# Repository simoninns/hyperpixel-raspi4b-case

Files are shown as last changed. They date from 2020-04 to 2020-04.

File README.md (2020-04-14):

# Hyperpixel 4.0 touch and Raspberry Pi 4B case (with Prusa MK3S bracket)
This project provides a 3D printable case for the Hyperpixel 4.0 touch display and Raspberry Pi 4 B.  The case features a universal mounting system; a bracket for the Prusa i3 MK3S/MMU2S is also provided.

Note: This project is GPLv3 open-source. The github repository for the model (containing the complete OpenSCAD project) can be found at https://github.com/simoninns/hyperpixel-raspi4b-case

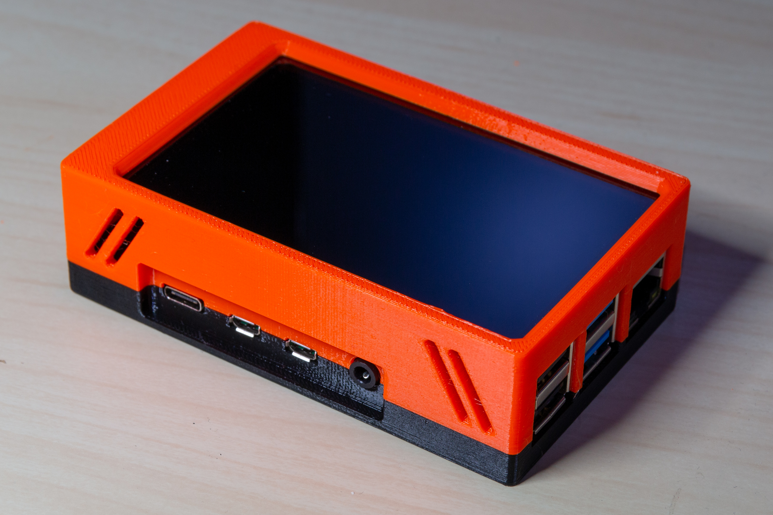
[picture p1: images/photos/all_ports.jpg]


# Overview

The case is designed in two parts (the upper and lower case) which snap together without the need for screws.  The Raspberry Pi and Hyperpixel display are held in place using the original mounting hardware provided with the Hyperpixel.

The project also includes an accurate model of the Raspberry Pi 4 B:

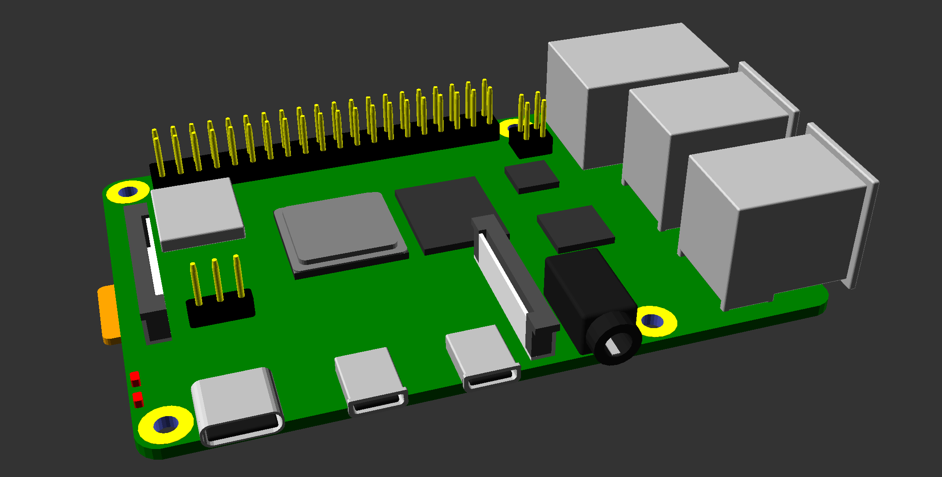
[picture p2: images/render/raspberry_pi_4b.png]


As well as an accurate model of the Hyperpixel 4.0 (rectangular) touch screen display:

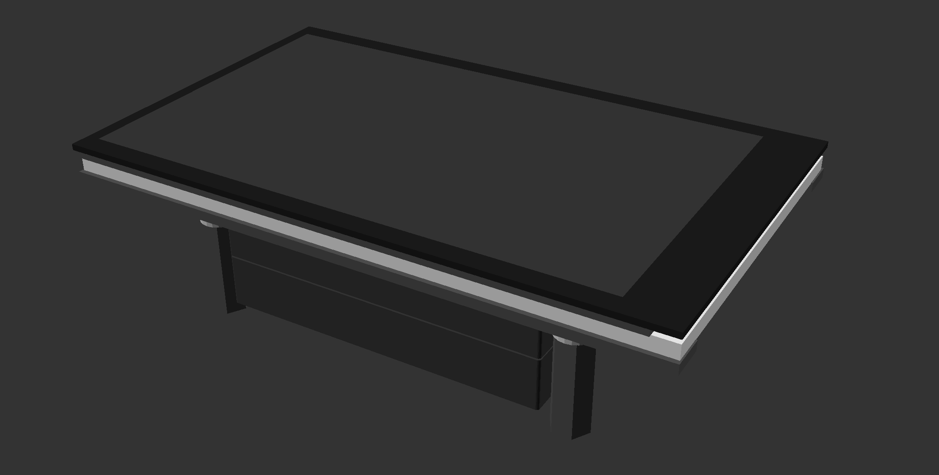
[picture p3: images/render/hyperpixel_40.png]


# Assembly instructions

The Hyperpixel 4.0 display should have both the GPIO extender and the 4 support posts mounted.  Attach the display to the Raspberry Pi.  Flip the joined boards screen down and place the lower case part onto the 4 posts (ensure the SD card is removed).  Screw together using the M2.5x5mm screws provided with the Hyperpixel display.  The SD card can be reinserted through the provided slot in the lower case.

If required the additional bracket (for the Prusa MK3S) can also be attached.  Ensure there are no screws in the lower case, then press the bracket into place.  The bracket should be secured using M2.5x8mm screws.  Note that the case is designed so brackets can be mounted on either side of the case in both up and down orientations.



The upper case is attached to the lower case by first lowering the connector-side of the case over the display (as it is too thick to be pressed straight down).  Then rotate the other side of the upper case over the display and clip the upper and lower cases together.

The lower case provides two 1.8mm holes for the LEDs.  You can optionally use two short lengths of transparent/clear 1.75mm filament to act as light-pipes.  These can be glued in place (using superglue) into the mount in the lower case.  This allows a wider viewing angle for the LEDs.

# Printing instructions

## Overview

The model has been printed and tested on the Prusa MK3S/MMU2S printer using PETG filament. All parts fit on a 20x20 printing bed.

The OpenSCAD source files provide a parameter interface that allows you to render either the whole model or the individual parts (ready for STL (or other 3D format) export).  This requires OpenSCAD 2019.05 or later.

## Recommended print settings
### Lower case
* Number required: 1
* Material: Prusament PETG (Prusa Jet Black)
* Layer: 0.20mm (Quality)
* Infill: 15%
* Supports: Support on build plate only
* Print time (approximate): 1h 51m
* Notes: None

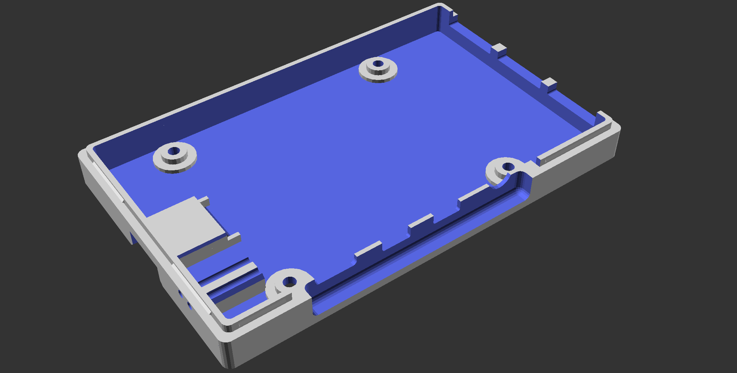
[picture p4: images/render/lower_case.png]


### Upper case
* Number required: 1
* Material: Prusament PETG (Prusa Orange)
* Layer: 0.20mm (Quality)
* Infill: 15%
* Supports: None
* Print time (approximate): 2h 24m
* Notes: None

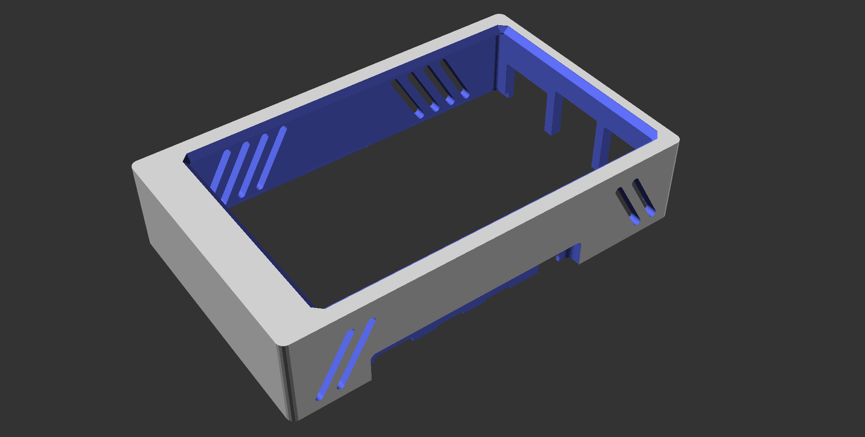
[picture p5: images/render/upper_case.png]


### Bracket
* Number required: 1
* Material: Prusament PETG (Prusa Orange)
* Layer: 0.20mm (Quality)
* Infill: 15%
* Supports: Everywhere
* Print time (approximate): 1h 49m
* Notes: Fits Prusa i3 MK3S and MMU2S

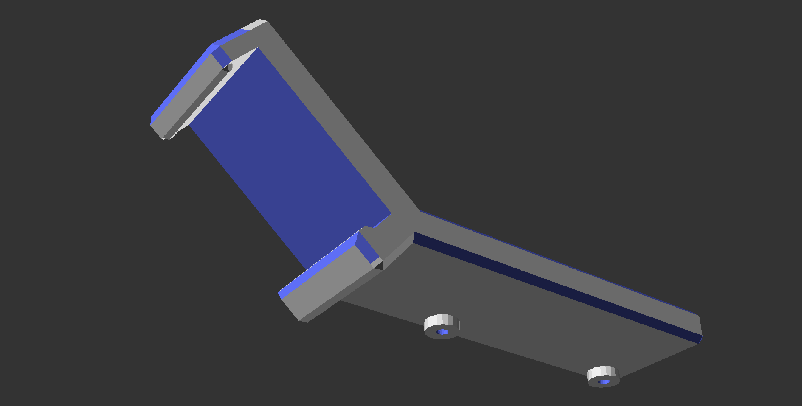
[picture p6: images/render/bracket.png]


### Desk stand
* Number required: 2
* Material: Prusament PETG (Prusa Orange)
* Layer: 0.20mm (Quality)
* Infill: 15%
* Supports: Everywhere
* Print time (approximate): 1h 1m
* Notes: Places the screen at a 30 degree angle for ease of use on a desk.

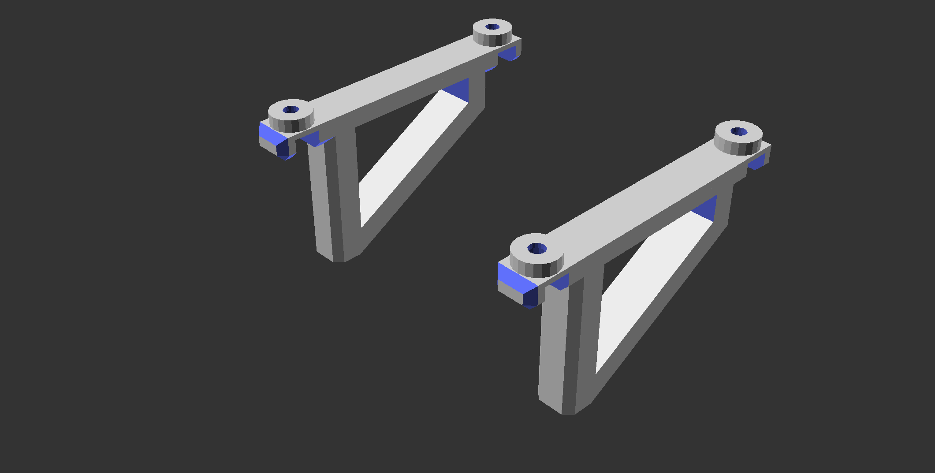
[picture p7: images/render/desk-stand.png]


# Author

The Hyperpixel 4.0 touch and Raspberry Pi 4B case is designed and maintained by Simon Inns.

# Licensing

## OpenSCAD source files - software license (GPLv3)

    This is free software: you can redistribute it and/or modify
    it under the terms of the GNU General Public License as published by
    the Free Software Foundation, either version 3 of the License, or
    (at your option) any later version.
    
    This program is distributed in the hope that it will be useful,
    but WITHOUT ANY WARRANTY; without even the implied warranty of
    MERCHANTABILITY or FITNESS FOR A PARTICULAR PURPOSE.  See the
    GNU General Public License for more details.
    
    You should have received a copy of the GNU General Public License
    along with this program.  If not, see <http://www.gnu.org/licenses/>.

## 3D model files - Creative Commons license (Creative Commons BY-SA 4.0)

Please see the following link for details: https://creativecommons.org/licenses/by-sa/4.0/

You are free to:

Share - copy and redistribute the material in any medium or format
Adapt - remix, transform, and build upon the material
for any purpose, even commercially.

This license is acceptable for Free Cultural Works.

The licensor cannot revoke these freedoms as long as you follow the license terms.

Under the following terms:

Attribution - You must give appropriate credit, provide a link to the license, and indicate if changes were made. You may do so in any reasonable manner, but not in any way that suggests the licensor endorses you or your use.

ShareAlike - If you remix, transform, or build upon the material, you must distribute your contributions under the same license as the original.

No additional restrictions - You may not apply legal terms or technological measures that legally restrict others from doing anything the license permits.

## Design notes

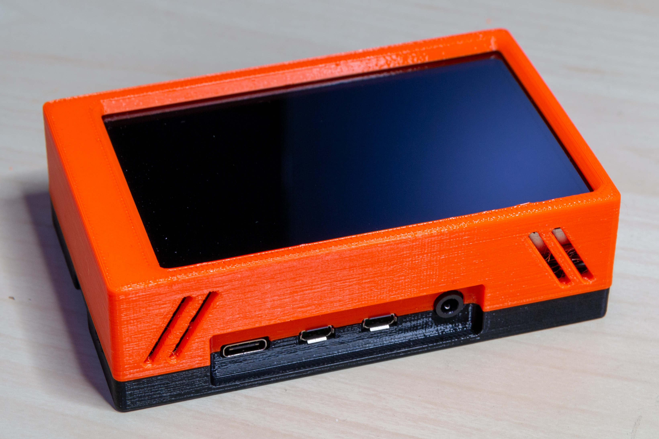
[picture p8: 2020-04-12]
images/photos/side_ports.jpg

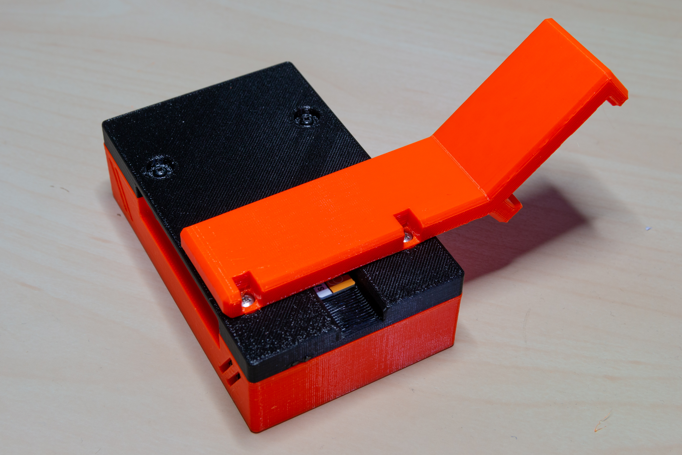
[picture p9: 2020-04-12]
images/photos/Back_with_bracket.jpg

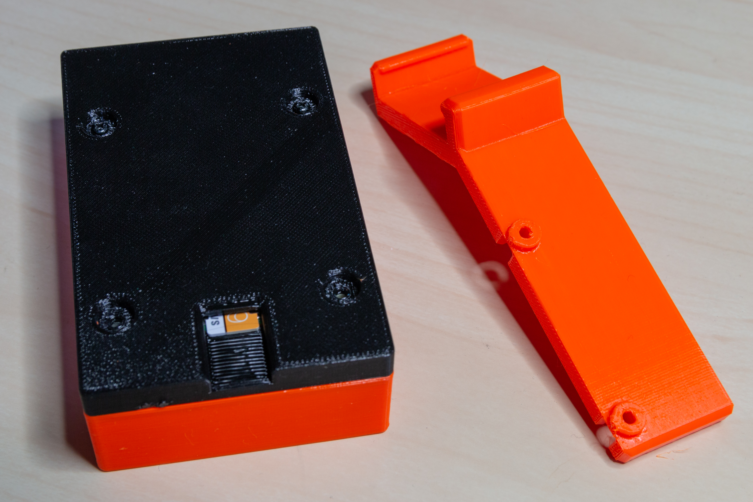
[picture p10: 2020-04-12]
images/photos/Back_unmounted_bracket.jpg

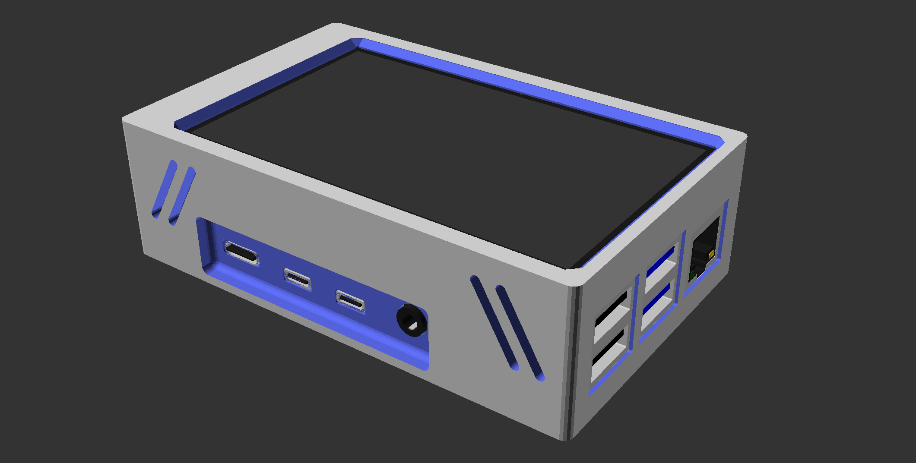
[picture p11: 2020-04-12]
images/render/complete_case.png

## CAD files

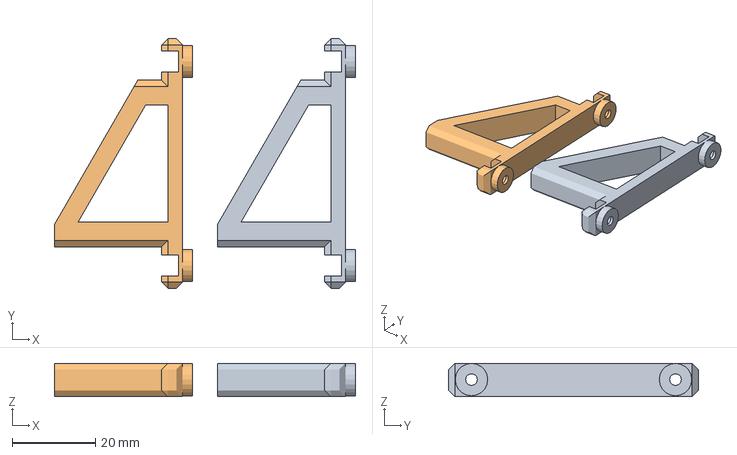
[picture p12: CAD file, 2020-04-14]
3mf/desk_stand.3mf
72.3 x 60.0 x 8.00 mm

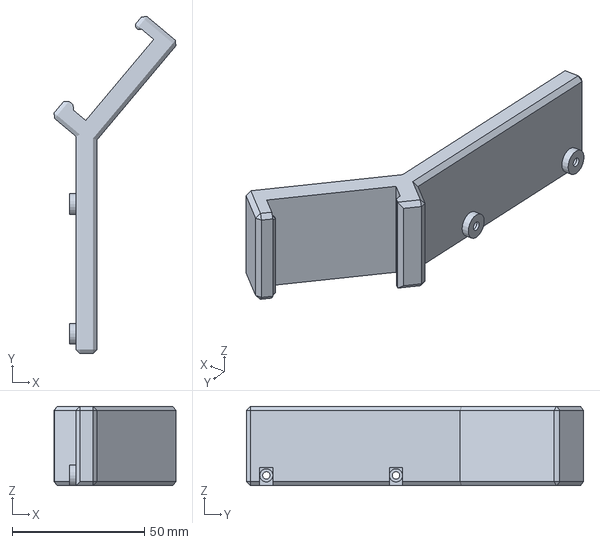
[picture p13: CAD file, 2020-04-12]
3mf/bracket.3mf
46.1 x 127.4 x 30.0 mm

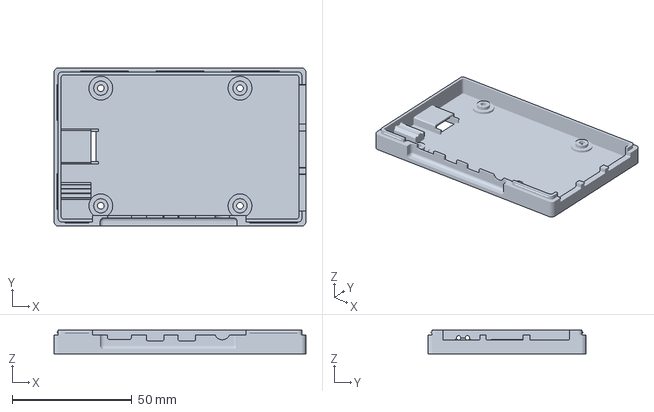
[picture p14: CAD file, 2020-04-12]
3mf/lower_case.3mf
105.0 x 66.0 x 10.0 mm

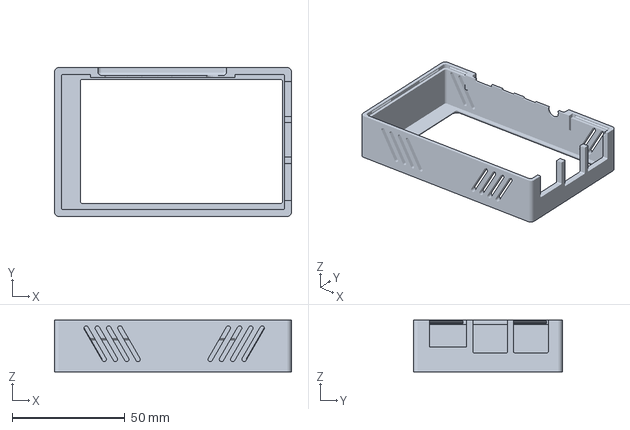
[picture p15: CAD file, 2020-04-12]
3mf/upper_case.3mf
105.0 x 66.0 x 23.0 mm

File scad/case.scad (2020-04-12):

/************************************************************************

	case.scad
    
	Raspberry Pi 4B / Hyperpixel 4.0 case
    Copyright (C) 2020 Simon Inns
    
    This program is free software: you can redistribute it and/or modify
	it under the terms of the GNU General Public License as published by
	the Free Software Foundation, either version 3 of the License, or
	(at your option) any later version.
    
    This program is distributed in the hope that it will be useful,
    but WITHOUT ANY WARRANTY; without even the implied warranty of
    MERCHANTABILITY or FITNESS FOR A PARTICULAR PURPOSE.  See the
    GNU General Public License for more details.
    
    You should have received a copy of the GNU General Public License
    along with this program.  If not, see <http://www.gnu.org/licenses/>.
	
    Email: simon.inns@gmail.com
    
************************************************************************/

include <BOSL/constants.scad>
use <BOSL/transforms.scad>
use <BOSL/shapes.scad>

// The connector cutouts are in a module so they can be common to both
// the upper and lower case parts
module connector_cutouts()
{
    // Recess
    move([3.25,-11.5,-2.5]) cuboid([57,10,3.5+10], center=false, fillet = 1.5);

    // Power in
    move([6.25,-3.5,1.5]) cuboid([10,4,3.5], center=false, fillet = 1, edges=EDGES_Y_ALL);

    // HDMI
    move([22,-3.5,1.5]) {
        move([0.5,0,-0.5]) cuboid([7.25,4,3.25], center=false, fillet = 0.5, edges=EDGES_Y_ALL);
        move([13.75,0,-0.5]) cuboid([7.25,4,3.25], center=false, fillet = 0.5, edges=EDGES_Y_ALL);
    }

    // Audio
    move([51,-3.5,1.5]) {
        move([3.125,1,3.125]) rotate([90,0,0]) cyl(h=6, d=6.5);
    }

    // USB2
    move([85,1.25,1.25]) {
        move([0,0,0]) cuboid([6,15.5,16.75], center=false, fillet = 0.5, edges=EDGES_X_ALL);
    }

    // USB3
    move([85,19.25,1.25]) {
        move([0,0,0]) cuboid([6,15.5,16.75], center=false, fillet = 0.5, edges=EDGES_X_ALL);
    }

    // Ethernet
    move([85,37.5,1.25]) {
        move([0,0,0]) cuboid([6,16.5,14.25], center=false, fillet = 0.5, edges=EDGES_X_ALL);
    }
}

// Render the lower case part
module lower_case()
{
    // Lower case
    difference() {
        union() {
            move([-15,-4,-4.5]) {
                difference() {
                    union() {
                        difference() {
                            move([-1,-1,0]) cuboid([105, 66, 8], center=false, fillet = 2, edges = EDGES_Z_ALL);
                            move([2,2,2]) cuboid([104 - 5, 66 - 6, 8], center=false, fillet = 1, edges = EDGES_Z_ALL);
                        }

                        union() {
                        // Add 2.5mm of thickness to the wall for side connectors
                        move([15,1,0]) cuboid([64,2.5,8], center=false);

                        // Pi stand-offs
                        move([15,4,-3]) {
                            // Internal stand-off, 2.5mm high (screw dia 2.8mm)
                            move([3.5,3.5,4]) cyl(h=2, d=10, center=false);
                            move([3.5 + 58,3.5,4]) cyl(h=2, d=10, center=false);
                            move([3.5,3.5 + 49,4]) cyl(h=2, d=10, center=false);
                            move([3.5 + 58,3.5 + 49,4]) cyl(h=2, d=10, center=false);
                        }

                        move([15,4,-3]) {
                            // Internal stand-off, 2.5mm high
                            move([3.5,3.5,6]) cyl(h=1.5, d=6, center=false);
                            move([3.5 + 58,3.5,6]) cyl(h=1.5, d=6, center=false);
                            move([3.5,3.5 + 49,6]) cyl(h=1.5, d=6, center=false);
                            move([3.5 + 58,3.5 + 49,6]) cyl(h=1.5, d=6, center=false);
                        }
                        }
                    }

                    // Mounting holes for Pi4 PCB
                    move([15,4,-6]) {
                        move([3.5,3.5,5]) cyl(h=6, d=2.8, center=false);
                        move([3.5 + 58,3.5,5]) cyl(h=6, d=2.8, center=false);
                        move([3.5,3.5 + 49,5]) cyl(h=6, d=2.8, center=false);
                        move([3.5 + 58,3.5 + 49,5]) cyl(h=6, d=2.8, center=false);
                    }

                    move([15,4,-7]) {
                        move([3.5,3.5,4.5]) cyl(h=5, d=8, center=false);
                        move([3.5 + 58,3.5,4.5]) cyl(h=5, d=8, center=false);
                        move([3.5,3.5 + 49,4.5]) cyl(h=5, d=8, center=false);
                        move([3.5 + 58,3.5 + 49,4.5]) cyl(h=5, d=8, center=false);
                    }

                    // LED holes
                    move([-8 +14,7.85 +4,2.25 +4.5]) {
                        xcyl(h=16, d = 1.8);
                    }
                    move([-8 +14,11.5 +4,2.25 +4.5]) {
                        xcyl(h=16, d = 1.8);
                    }
                }
            }

            // Add a lip to mate with the upper case
            move([-15,-4,3.5+2]) {
                difference() {
                    // Lip
                    move([0.75,0.75,-2]) cuboid([104 - 2.5, 64 - 1.5, 2], center=false, fillet = 1.5, edges = EDGES_Z_ALL);
                    move([2,2,-3]) cuboid([104 - 5, 64 - 4, 4], center=false, fillet = 1, edges = EDGES_Z_ALL);
                    move([15,0,-6.5]) cuboid([64,5,8], center=false); // Not around side connectors
                    move([100,6,-6.5]) cuboid([5,52,8], center=false); // Not around front connectors
                }

                // Clips
                move([3.5,1,-1.75]) rotate([45,0,0]) cuboid([10,1,1], center=false);
                move([80.5,1,-1.75]) rotate([45,0,0]) cuboid([20,1,1], center=false);

                move([10,63,-1.75]) rotate([45,0,0]) cuboid([20,1,1], center=false);
                move([41.5,63,-1.75]) rotate([45,0,0]) cuboid([20,1,1], center=false);
                move([73,63,-1.75]) rotate([45,0,0]) cuboid([20,1,1], center=false);

                move([0.25,6,-1]) rotate([0,45,0]) cuboid([1,15,1], center=false);
                move([0.25,43,-1]) rotate([0,45,0]) cuboid([1,15,1], center=false);
            }
        }

        // Add the connector cutouts
        connector_cutouts();

        // SD card cutout
        move([-8,28.2,-2.5]) cuboid([19,12.5,6]);
        move([-7,28.2,-6.5]) cuboid([20,14.5,6], chamfer = 1);
    }

    // SD card housing
    move([-15,28.2,-5]) {
        move([2,-6.25,2.5 + 3]) cuboid([12.5,12.5,1], center=false);
        move([2,-7.25,2.5]) cuboid([12.5,1,4], center=false, chamfer = 0.5, edges = EDGE_TOP_FR);
        move([2,6.25,2.5]) cuboid([12.5,1,4], center=false, chamfer = 0.5, edges = EDGE_TOP_BK);

        move([5,-7.25,2.5]) cuboid([12.5,1,2], center=false);
        move([5,6.25,2.5]) cuboid([12.5,1,2], center=false);
    }

    // Light pipe mount for LEDs (use 1.75mm clear filament for pipes)
    difference() {
        move([-7,9.65,0]) {
            cuboid([13,7,4.5], chamfer = 1, edges= EDGE_TOP_BK+EDGE_TOP_FR);
        }
        
        move([-8,7.85,2.25]) {
            xcyl(h=16, d = 1.8);
        }
        move([-8,11.5,2.25]) {
            xcyl(h=16, d = 1.8);
        }
    }
}

// Render the upper case part
module upper_case(lift)
{
    // Upper case
    difference() {
        union() {
            move([-15,-4,3.5 + lift]) {
                difference() {
                    move([-1,-1,0]) cuboid([105, 66, 23], center=false, fillet = 2, edges = EDGES_Z_ALL);
                    move([2,2,-2]) cuboid([104 - 5, 66 - 6, 23], center=false, fillet = 1, edges = EDGES_Z_ALL);

                    // Screen cut out
                    move([((104 - 90) / 2) + 4 - 2,((64 - 54) / 2) - 0.25 - 2,20.9]) cuboid([90 - 1.5 + 4, 54 + 4, 8], center=false, chamfer = 2);

                    // Square the inner edge of the cutout
                    move([((104 - 90) / 2) + 4 - 0.5,((64 - 54) / 2) - 0.25 - 0.5,19]) cuboid([90 - 1.5 + 1, 54 + 1, 6], center=false, chamfer = 0.5);
                }
            }

            // Add 1.5mm of thickness to the wall for side connectors
            move([0,-2,3.5 + lift]) cuboid([64,1.5,8], center=false);

            // Chamfer it at 45 degrees for easier printing
            move([32,-1.25,11.5+lift]) rotate([0,0,90]) right_triangle([1.5,64,1], center=false);
        }

        // Remove material to allow mating with lower case
        move([-15,-4,4.5 + lift]) {
            difference() {
                move([0.75,0.75,-3]) cuboid([104 - 2.5, 64 - 1.5, 4], center=false, fillet = 1.5, edges = EDGES_Z_ALL);
                move([15,0,-6.5]) cuboid([64,5,8], center=false); // Not around side connectors
                move([100,6,-6.5]) cuboid([5,51,8], center=false); // Not around front connectors
            }
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

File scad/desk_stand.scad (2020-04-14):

/************************************************************************

	prusa_mk3s_bracket.scad
    
	Raspberry Pi 4B / Hyperpixel 4.0 case
    Copyright (C) 2020 Simon Inns
    
    This program is free software: you can redistribute it and/or modify
	it under the terms of the GNU General Public License as published by
	the Free Software Foundation, either version 3 of the License, or
	(at your option) any later version.
    
    This program is distributed in the hope that it will be useful,
    but WITHOUT ANY WARRANTY; without even the implied warranty of
    MERCHANTABILITY or FITNESS FOR A PARTICULAR PURPOSE.  See the
    GNU General Public License for more details.
    
    You should have received a copy of the GNU General Public License
    along with this program.  If not, see <http://www.gnu.org/licenses/>.
	
    Email: simon.inns@gmail.com
    
************************************************************************/

include <BOSL/constants.scad>
use <BOSL/transforms.scad>
use <BOSL/shapes.scad>

module desk_stand_leg()
{
    // Render the desk for reference
    //move([40,30,-31]) rotate([30,0,0]) cuboid([100,100,10]);

    move([0,3.5,-8.5]) {
        difference() {
            lugx = -26.1;
            union() {
                move([-30,-5.5,-1]) cuboid([8,60,5], chamfer = 1.5, edges=EDGES_ALL-EDGE_TOP_LF-EDGE_TOP_RT, center=false);
                move([-30,4.5,-36]) cuboid([8,40,40], center=false, chamfer = 1.5);

                // Mounting lugs
                move([lugx,0,3 + 1.4]) cyl(h=4, d=7.8);
                move([lugx,49,3 + 1.4]) cyl(h=4, d=7.8);
            }

            // Cut angle into stand
            move([-26,30,-44]) rotate([30,0,0]) cuboid([12,100,50]);

            // Cut out centre
            difference() {
                move([-26,24.5,-14.5]) cuboid([12,28,30]);
                move([-26,25,-30]) rotate([30,0,0]) cuboid([14,60,30]);
            }

            // Chamfer back edge
            move([-26,7,-29.25]) cuboid([14,10,5]);

            // Screw shaft holes
            move([lugx,0,3]) cyl(h=10, d=2.8);
            move([lugx,49,3]) cyl(h=10, d=2.8);

            // Screw head recess holes
            move([lugx,0,-12 + 10.5]) cyl(h=14, d=5);
            move([lugx,49,-12 + 10.5]) cyl(h=14, d=5);

            move([lugx - 2,0,-12 + 8]) cuboid([14, 5, 14]);
            move([lugx - 2,49,-12 + 8]) cuboid([14, 5, 14]);
        }
    }
}

// Desk stand angle is 30 degrees
module desk_stand(number)
{
    if (number == "2") {
        move([29.5,0,0]) desk_stand_leg();
        move([29.5 + 58,0,0]) desk_stand_leg();
    } else {
        move([29.5,0,0]) desk_stand_leg();
    }
}

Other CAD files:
scad/main.scad
scad/prusa_mk3s_bracket.scad
scad/BOSL/acme_screws.scad
scad/BOSL/beziers.scad
scad/BOSL/compat.scad
scad/BOSL/constants.scad
scad/BOSL/convex_hull.scad
scad/BOSL/debug.scad
scad/BOSL/involute_gears.scad
scad/BOSL/joiners.scad
scad/BOSL/linear_bearings.scad
scad/BOSL/masks.scad
scad/BOSL/math.scad
scad/BOSL/metric_screws.scad
scad/BOSL/nema_steppers.scad
scad/BOSL/paths.scad
scad/BOSL/phillips_drive.scad
scad/BOSL/quaternions.scad
scad/BOSL/shapes.scad
scad/BOSL/sliders.scad
scad/BOSL/threading.scad
scad/BOSL/torx_drive.scad
scad/BOSL/transforms.scad
scad/BOSL/triangulation.scad
scad/BOSL/wiring.scad
scad/hyperpixel/hyperpixel.scad
scad/rasppi4b/components.scad
scad/rasppi4b/connectors.scad
scad/rasppi4b/pcb.scad
scad/rasppi4b/rasppi4b.scad
stl/bracket.stl
stl/desk_stand.stl
stl/lower_case.stl
stl/upper_case.stl

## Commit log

2020-04-11 Adding current project files
    [acme_screws.scad, beziers.scad, case.scad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]
2020-04-11 Updated design, corrected Hyperpixel model, added case vents
    [case.scad, hyperpixel.scad]
2020-04-11 Modified case clipping design, corrected measurements. Added more vents.
    [case.scad, hyperpixel.scad, main.scad]
2020-04-11 Bug fix and added image files
    [case.scad, lower_case.3mf, lower_case.stl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]
2020-04-11 Improved clips, alignment and strength
    [case.scad, hyperpixel.scad, lower_case.stl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]
2020-04-11 More mods, but clips/recesses unprintable
    [case.scad, lower_case.stl, main.scad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]
2020-04-12 Thicker walls, better internal design - chamfered display cutout
    [case.scad, lower_case.stl, upper_case.stl]
2020-04-12 Updated 3mf project files and PNG images
    [lower_case.3mf, upper_case.3mf]
2020-04-12 Added bracket for the Prusa i3 MK3S/MMU2S printer
    [bracket.3mf, bracket.stl, main.scad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]
2020-04-12 Corrected bracket dimensions and modified for easier printing
    [bracket.3mf, bracket.stl, prusa_mk3s_bracket.scad]
2020-04-12 Added photographs and rearranged images folder
    [bracket.3mf]
2020-04-12 Updated readme. Added bracket render
2020-04-14 Added desk-stand to OpenSCAD code
    [desk_stand.scad, main.scad]
2020-04-14 Updated readme and desk stand support files
    [desk_stand.3mf, desk_stand.stl]
